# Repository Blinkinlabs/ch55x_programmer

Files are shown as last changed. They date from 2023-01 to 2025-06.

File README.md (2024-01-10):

# CH55x Reset Controller

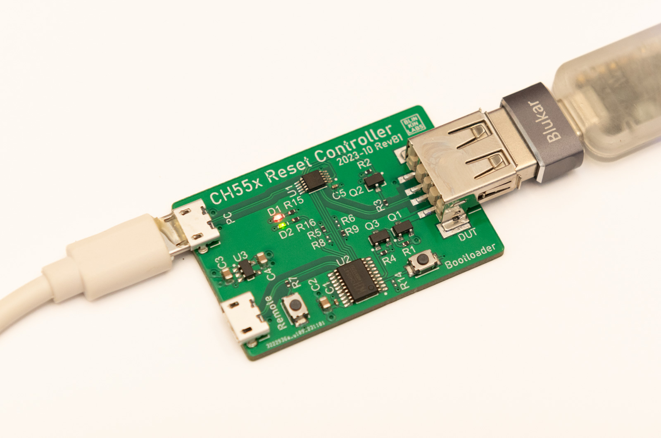
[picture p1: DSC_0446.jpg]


Get yours here: https://shop-nl.blinkinlabs.com/products/ch55x-reset-controller

The CH55x Reset Controller is a one-touch solution for putting WCH CH554 and CH552 microcontrollers into bootloader mode. The reset controller performs a simple sequence to achieve this:

1.    Disconnects both power and USB data lines from the devive
2.    Connects a 10k resistor from 3.3V to the D+ USB line
3.    Connects the power and USB data lines to the device
4.    After a short delay, disconnects the 10k resistor from the device

Notes:

*    This will only work with USB-powered CH55x devices, if the device has power from a battery or other power source, the CH55x will not reset
*    Connect the computer to the 'DUT IN' micro USB port
*    Connect your WCH CH55x device to the 'DUT OUT' USB A port
*    This board was designed to work with 3.3V powered CH55x devices. It may work with 5V powered devices, but this is untested.
*    The board includes a 'control in' connection for remotely controlling the bootloader sequence, however this is not supported in the software for the device.

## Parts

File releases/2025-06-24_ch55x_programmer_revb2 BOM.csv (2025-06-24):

Designator | Quantity | Comment | Description | Manufacturer 1 | Manufacturer Part Number 1 | Supplier 1 | Supplier Part Number 1 | Supplier 2 | Supplier Part Number 2 | Pins | Case/Package | Footprint | Library Name
C1, C5 | 2 | 100nF | CAP SMD 100nF 10% 50V X5R 0402 | Yageo Group | CC0402KRX5R9BB104 | DigiKey | 311-3342-2-ND |  |  | 2 | 0402 | CAPC1005X06L | blinkinlabs.DbLib
C2, C3, C4 | 3 | 10uF | CAP SMD 10uF 10% 25V X5R 0805 | Yageo | CC0805KRX5R8BB106 | Digikey | 13-CC0805KRX5R8BB106TR-ND |  |  | 2 | 0805 | CAPC2012X10L | blinkinlabs.DbLib
D1 | 1 | BL-HUB37A-AV-TRB | LED, 0402, Super Red, 50mcd@20mA, 627~637nm | BrtLed | BL-HUB37A-AV-TRB | LCSC | C165980 |  |  | 2 | 0402 | BL-Hxx37A-AV-TRB | blinkinlabs.DbLib
D2 | 1 | BL-HGE37A-AV-TRB | LED, 0402, Super Yellow Green, 35mcd@20mA, 566~576nm | BrtLed | BL-HGE37A-AV-TRB | LCSC | C165979 |  |  | 2 | 0402 | BL-Hxx37A-AV-TRB | blinkinlabs.DbLib
J1, J3 | 2 | A01SB741B1-267 | Micro USB B type ?????? | Unknown/Generic | Unknown/Generic |  |  |  |  | 11 | SMD | A01SB741B1-267 | blinkinlabs.DbLib
J2 | 1 | 904-241A2032S10100 | USB A connector, SMD, no tabs | Jing Extension of the Electronic | 904-241A2032S10100 | LCSC | C42605 |  |  | 6 | SMD | C42605 | blinkinlabs.DbLib
Q1, Q2 | 2 | AO3401A | MOSFET P-CH 30V 4A SOT23-3L | Alpha & Omega Semiconductor | AO3401A | DigiKey | 785-1001-2-ND | LCSC | C15127 | 3 | SOT-23-3 | AO-SOT-23-3L_V | blinkinlabs.DbLib
Q3 | 1 | AO3400A | MOSFET N-CH 30V 5.7A SOT23-3L | Alpha & Omega Semiconductor | AO3400A | Digikey | 785-1000-2-ND | LCSC | C20917 | 3 | SOT-23-3 | AO-SOT-23-3L_V | blinkinlabs.DbLib
R1, R2, R3, R4, R5, R7, R9 | 7 | 10K | RES SMD 10K OHM 5% 1/16W 0402 | Yageo Group | RC0402JR-0710KL | Digikey | 311-10KJRTR-ND |  |  | 2 | 0402 | ERJ2G(0402)_L | blinkinlabs.DbLib
R15, R16 | 2 | 1K | RES SMD 1K OHM 5% 1/16W 0402 | Yageo Group | RC0402JR-071KL | Digikey | 311-1.0KJRTR-ND |  |  | 2 | 0402 | ERJ2G(0402)_L | blinkinlabs.DbLib
SW1, SW2 | 2 | TS-1185-B-A-B-A | Tactile switch, SPST, 3x4mm, 50mA 160gf 12V, no mounting pins | XKB Connectivity | TS-1185-B-A-B-A | LCSC | C561517 |  |  | 2 | SMD | TS-1185 | blinkinlabs.DbLib
U1 | 1 | FSUSB42MUX | USB Switch IC 1 Channel 10-MSOP | onsemi | FSUSB42MUX | Digikey | FSUSB42MUXCT-ND | LCSC | C11355 | 10 | 10-TFSOP, 10-MSOP (0.118", 3.00mm Width) | FP-846AP-MFG | blinkinlabs.DbLib
U2 | 1 | CH554T | 8-bit enhanced USB microcontroller | WCH | CH554T | LCSC | C2928938 |  |  | 20 | TSSOP-20 | TSOP65P660X110-20N | blinkinlabs.DbLib
U3 | 1 | BL8568CB5ATR33 | 500mA High PSRR, Linear Regulator, w. Output Discharge | Shanghai Belling | BL8568CB5ATR33 | LCSC | C243122 |  |  | 5 | SOT-23-5 | SOT95P280X130-5N-2 | blinkinlabs.DbLib

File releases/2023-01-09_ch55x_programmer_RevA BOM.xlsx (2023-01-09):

Designator | Comment | Manufacturer | PartNumber | Digi-Key Part Number | LCSC PartNumber | Description | Pins | Quantity | Model:Footprint | Case/Package
C1, C5 | 0.10uF | Murata Electronics North America | GRM155R71C104KA88J | 490-6328-1-ND |  | CAP CER 0.1UF 16V X7R 0402 | 2 | 2 |  | 0402
C2, C3 | 10uF | Murata Electronics North America | GRM21BR71A106KE51K, GRM21BR61C106ME15L | 490-6477-1-ND, 490-6474-1-ND |  | CAP CER 10UF 10V X7R 0805, CAP CER 10UF 16V X5R 0805 | 2 | 2 |  | 0805
C4 | 10uF | Murata Electronics North America | GRM188R61A106ME69D | 490-10475-1-ND |  | CAP CER 10UF 10V X5R 0603 | 2 | 1 |  | 0603
J1 | DUT_IN | Unknown/Generic | Unknown/Generic |  |  | Micro USB B type 四脚全插牛角 | 11 | 1 | micro usb B type
J2 | DUT_OUT | LC (立创) | C42605 |  |  | USB A connector, SMD, no tabs | 6 | 1 | USB-A SMD
J3 | CONTROL_IN | Unknown/Generic | Unknown/Generic |  |  | Micro USB B type 四脚全插牛角 | 11 | 1 | micro usb B type
Q1, Q2 | AO3401A | Alpha and Omega |  |  |  | P-Channel MOSFET, 30 V, 4 A, -55 to 150 degC, 3-Pin SOT-23-3L, RoHS, Tape and Reel | 3 | 2 | SOT23, 3-Leads, Body 3.1x1.8mm, Pitch 0.95mm
Q3 | AO3400A |  |  |  |  | MOSFET N-CH 30V 5.7A SOT23 | 3 | 1 |  | SOT-23
R1, R2, R3, R4, R7, R8, R9 | 10k | Panasonic Electronic Components | ERJ-2GEJ103X | P10KJCT-ND |  | RES SMD 10K OHM 5% 1/10W 0402 | 2 | 7 |  | 0402
R5, R6, R10, R11, R12, R13, R14 | DNP |  | DNP |  |  |  | 2 | 7 |  | 0402
SW1 | BOOTLOADER | XKB | TS-1185 |  |  | Tact Switch, 3x4mm, no alignment pin, turtle style | 2 | 1 | 3x4x2mm Tact Switch, no alignment pin
SW2 | TS-1185 | XKB | TS-1185 |  |  | Tact Switch, 3x4mm, no alignment pin, turtle style | 2 | 1 | 3x4x2mm Tact Switch, no alignment pin
U1 | FSUSB42MUX |  |  |  |  | IC USB SWITCH DPDT 10MSOP | 10 | 1 |  | MSOP
U2 | CH554T | WCH | CH554T |  |  | 8-bit enhanced USB microcontroller | 20 | 1 | TSOP, 20-Leads, Body 6.50x4.40mm, Pitch 0.65mm, IPC Medium Density
U3 | BL8568CB5ATR33 | Shanghai Belling | BL8568CB5ATR33 |  | C243122 | 500mA High PSRR, Linear Regulator, w. Output Discharge | 5 | 1 | SOT23, 5-Leads, Body 2.90x2.80mm, Pitch 0.95mm, IPC Medium Density

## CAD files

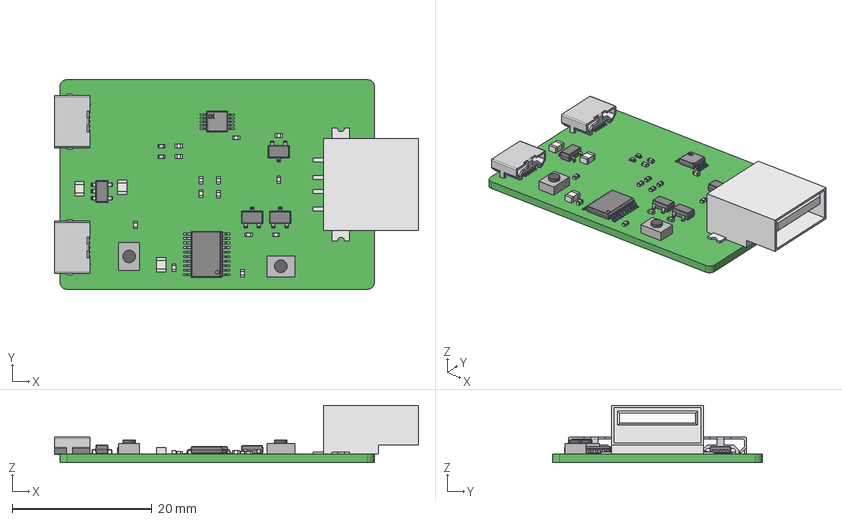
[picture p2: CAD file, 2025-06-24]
releases/2025-06-24_ch55x_programmer_revb2.step
52.1 x 30.0 x 8.23 mm
Extruded x 61
Leader x 34
A01SB741B1-267 v1 x 2
Leg
On-Semi Yury adjustable
On-Semi Yury adjustable - Copy
C42605 v2

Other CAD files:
releases/2023-12-19_ch55x_programmer_revb2.step
releases/2023-11-15_ch55x_programmer_revb2.step
releases/2023-10-30_c55x_programmer_revb.step
releases/2023-10-31_ch55x_programmer_revb1.step
releases/2023-01-09_ch55x_programmer_RevA.step

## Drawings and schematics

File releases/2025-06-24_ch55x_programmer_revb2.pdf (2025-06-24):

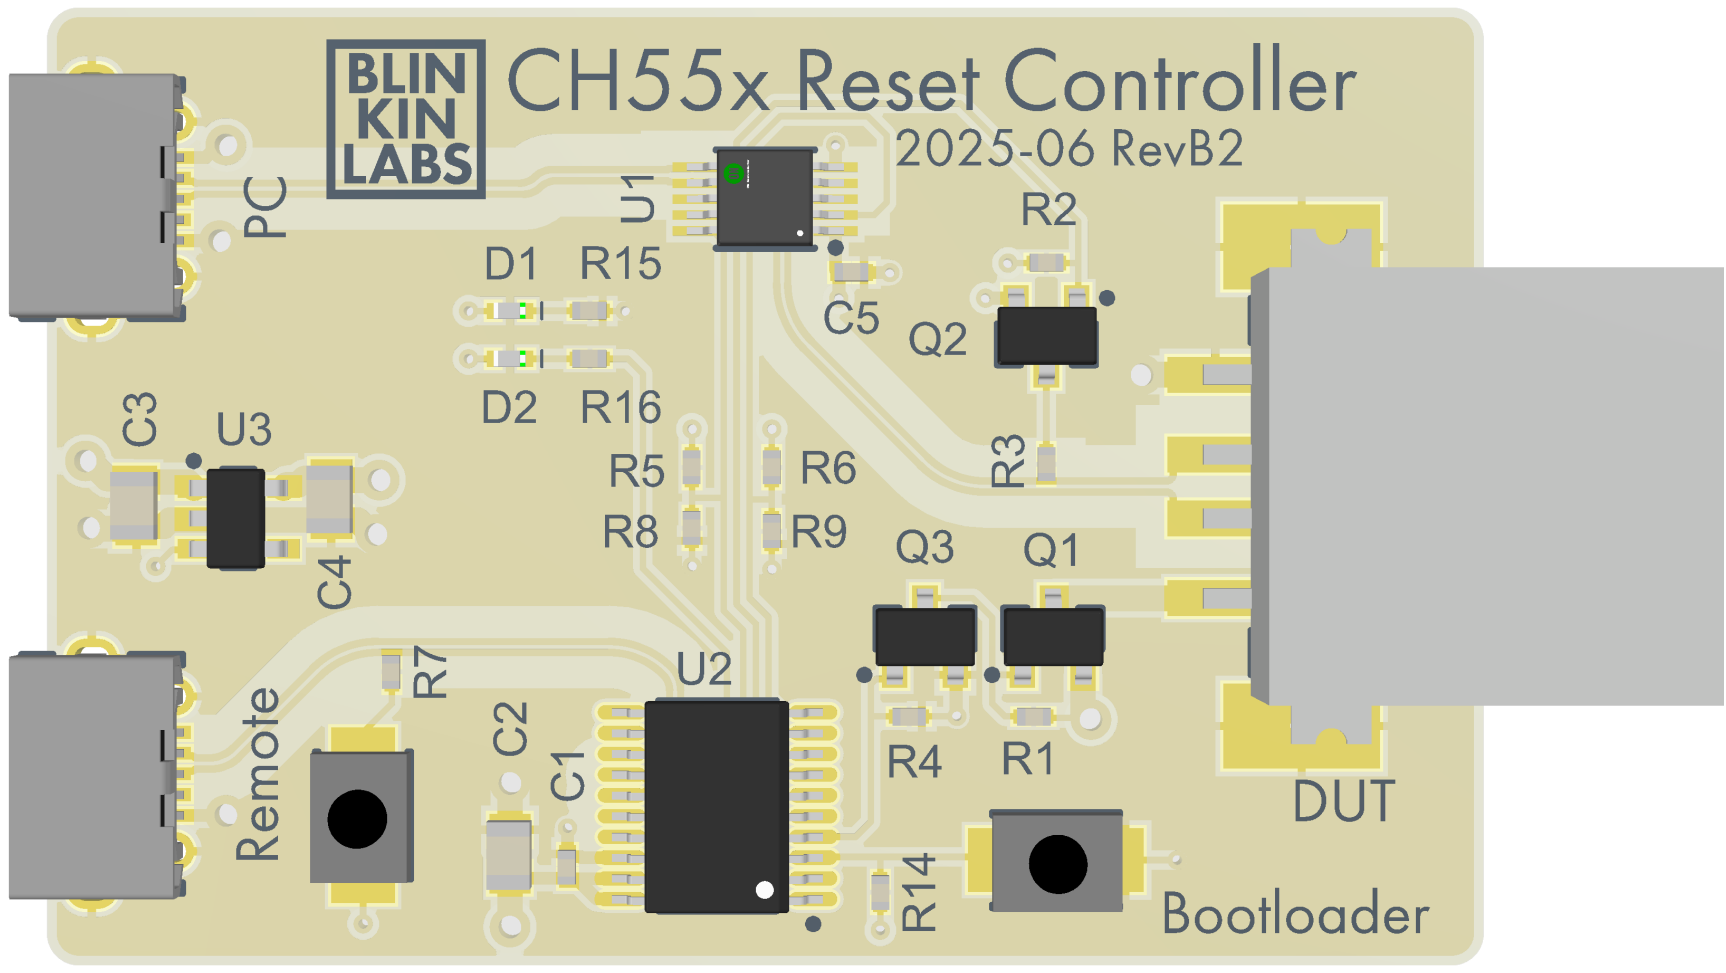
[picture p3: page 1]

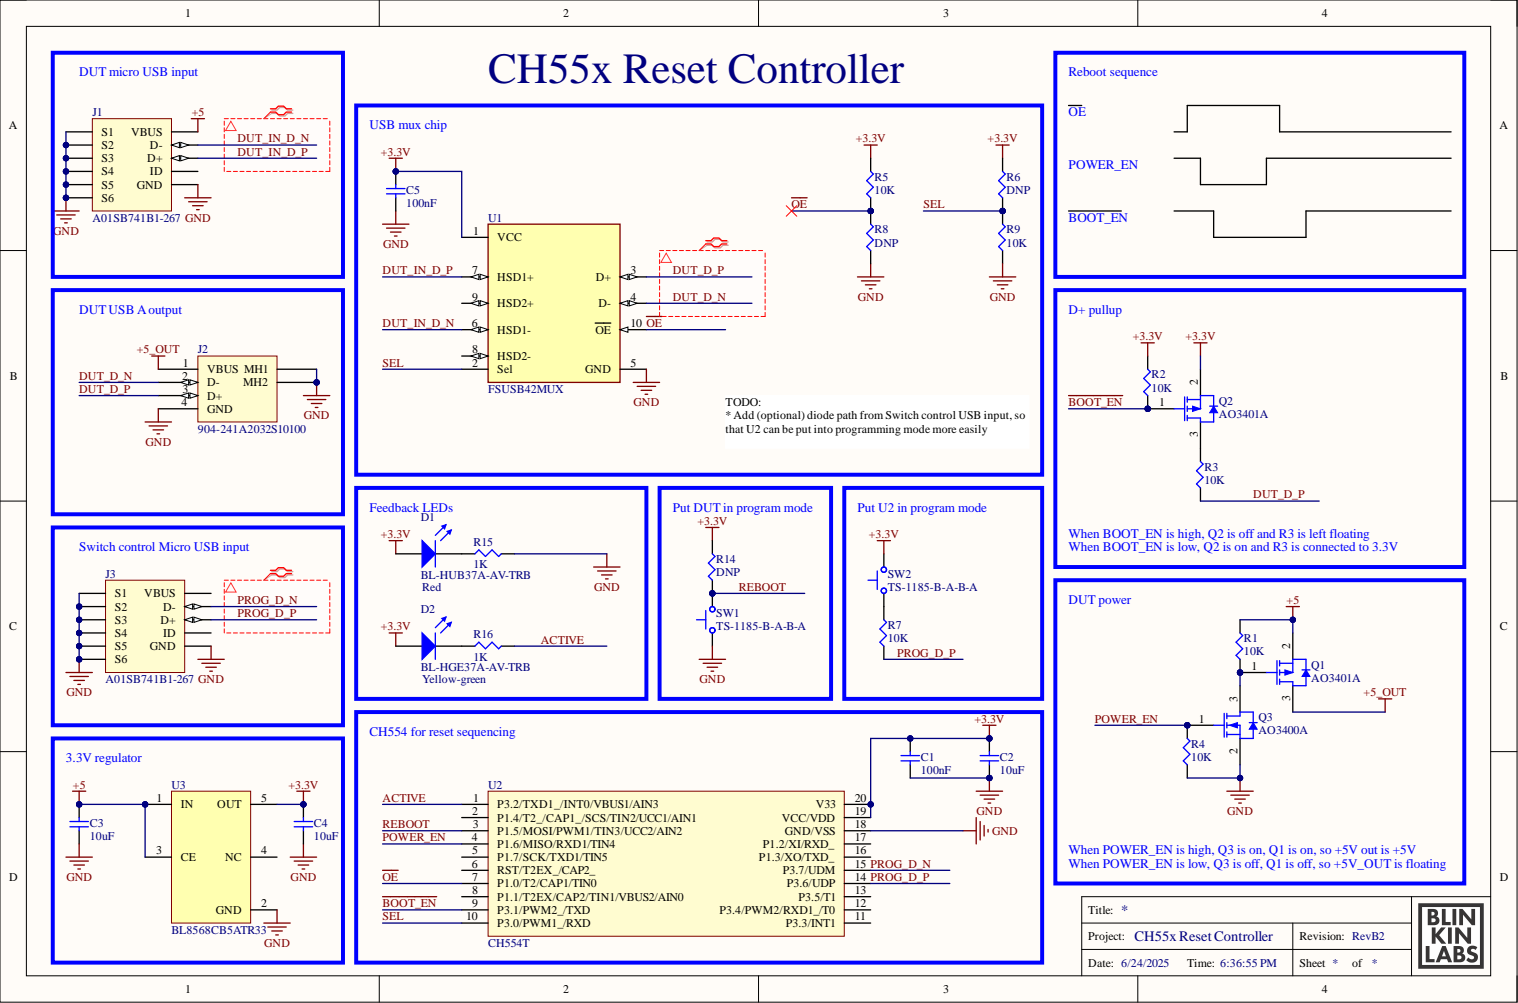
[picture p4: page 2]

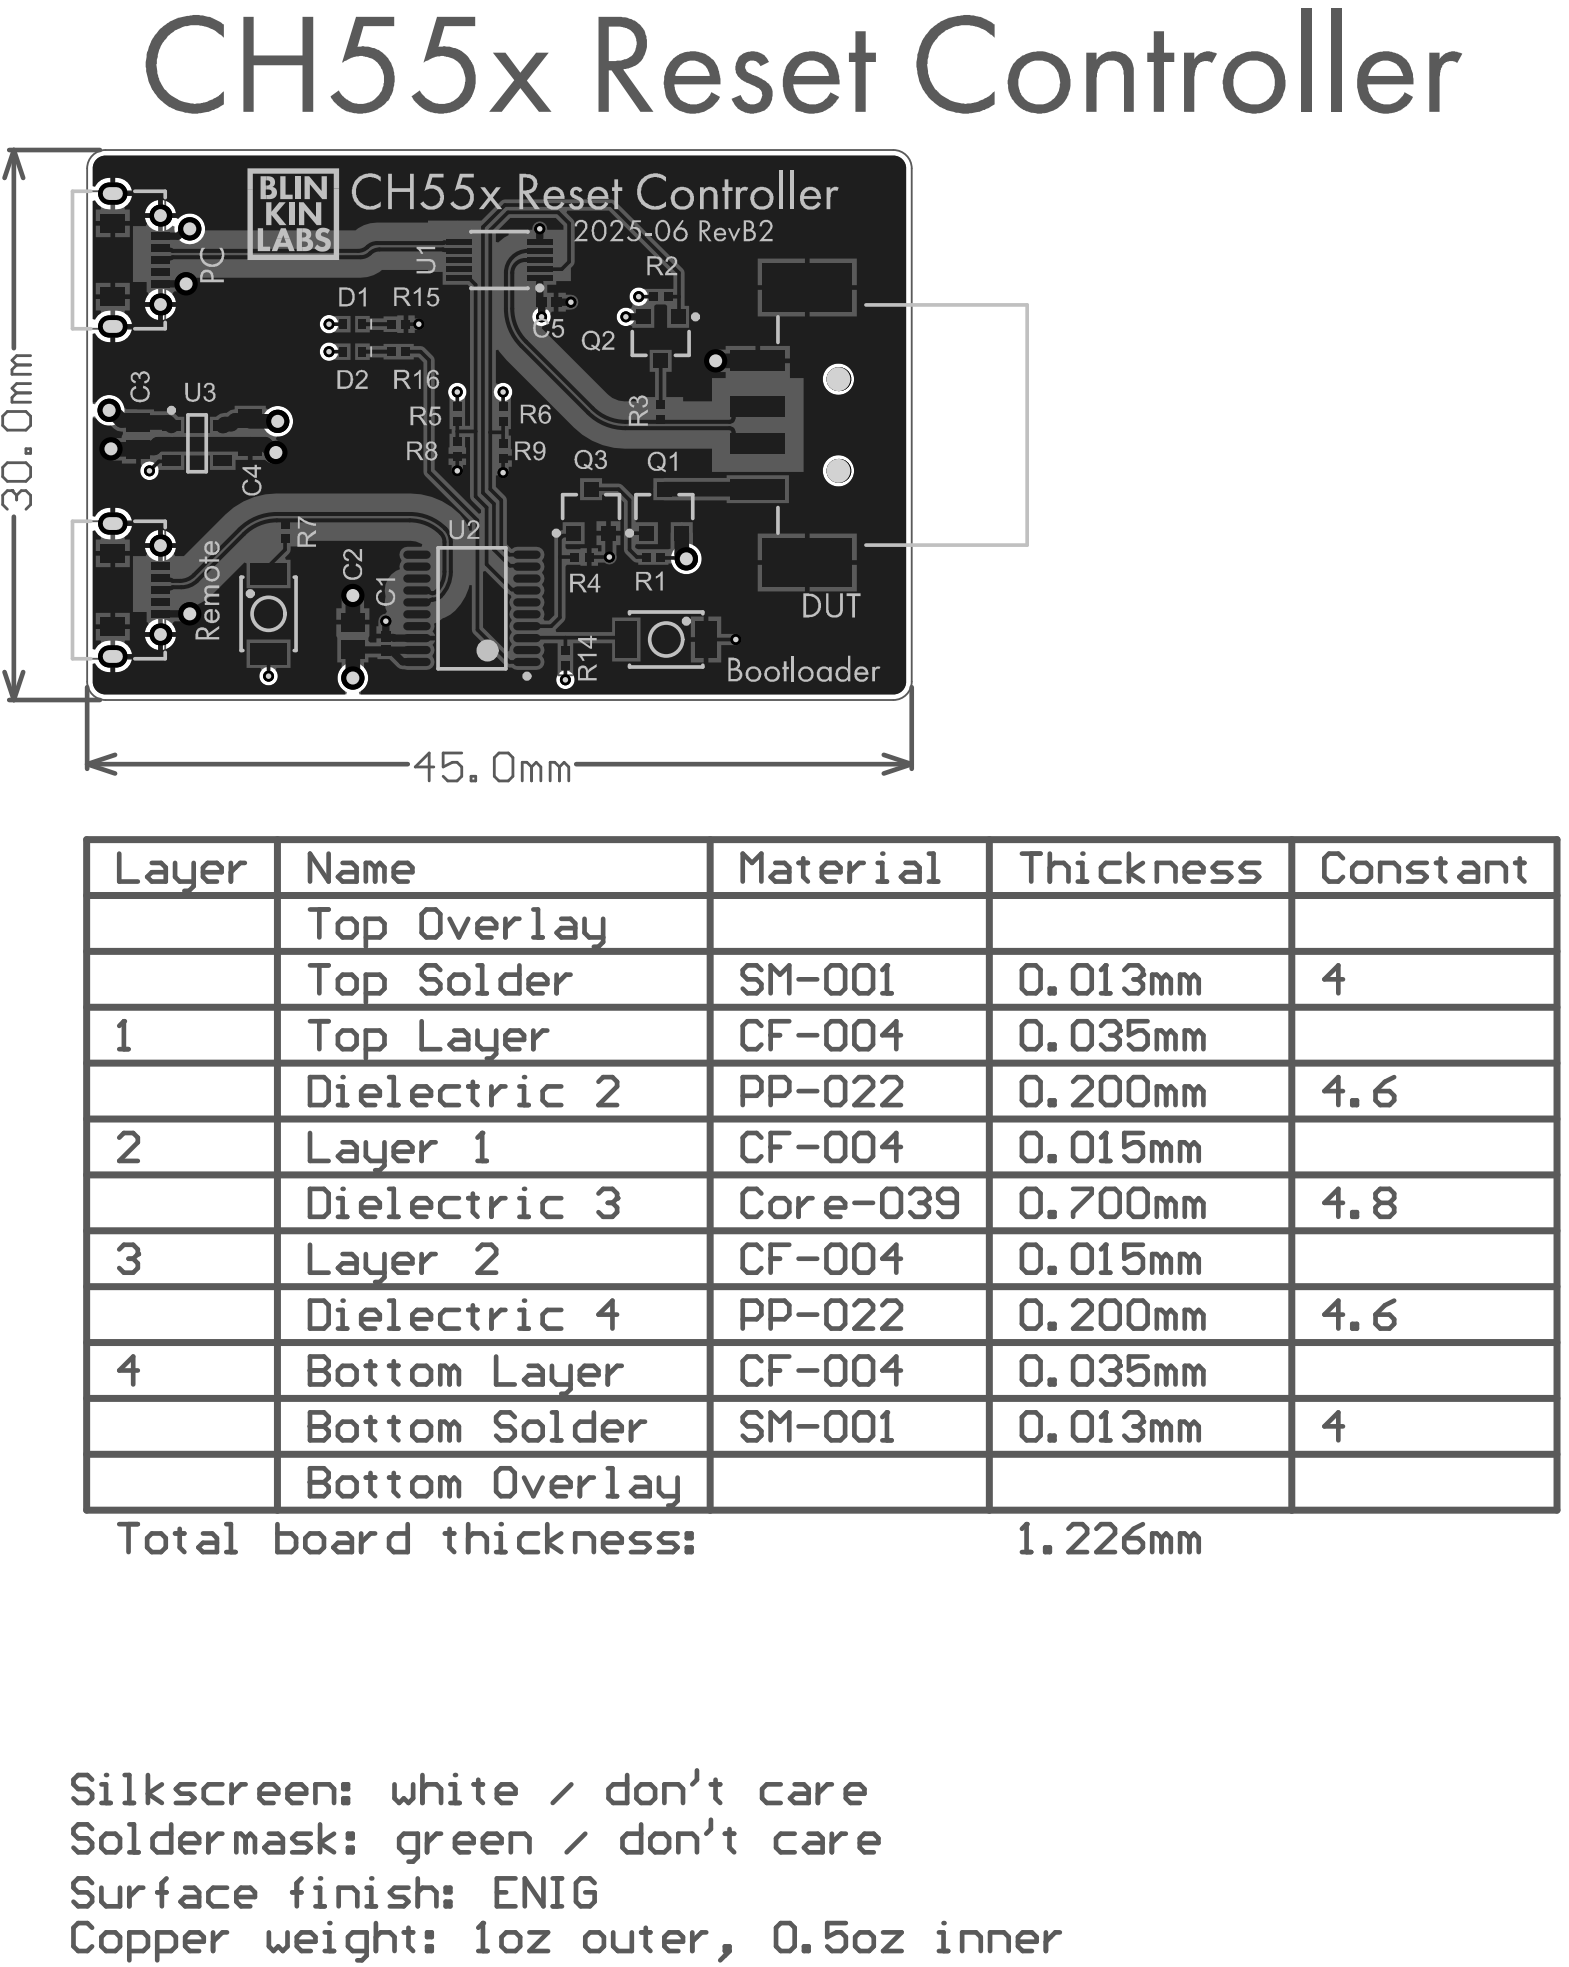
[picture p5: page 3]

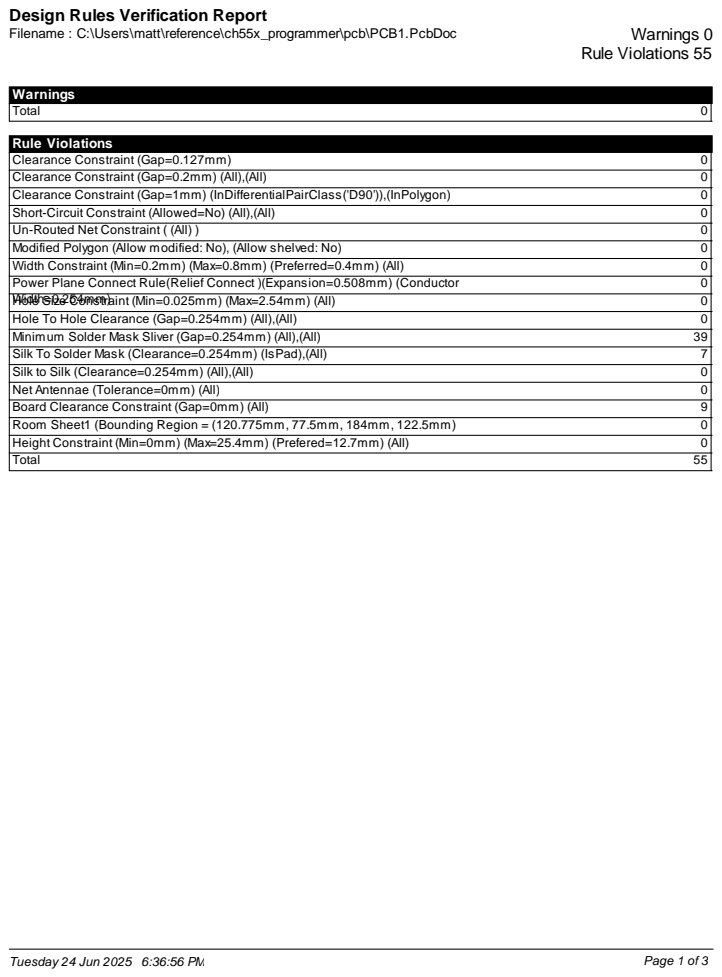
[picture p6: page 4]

Design Rules Verification Report

Rule Violations
Power Plane Connect Rule(Relief Connect )(Expansion=0.508mm) (Conductor
Width=0.254mm)

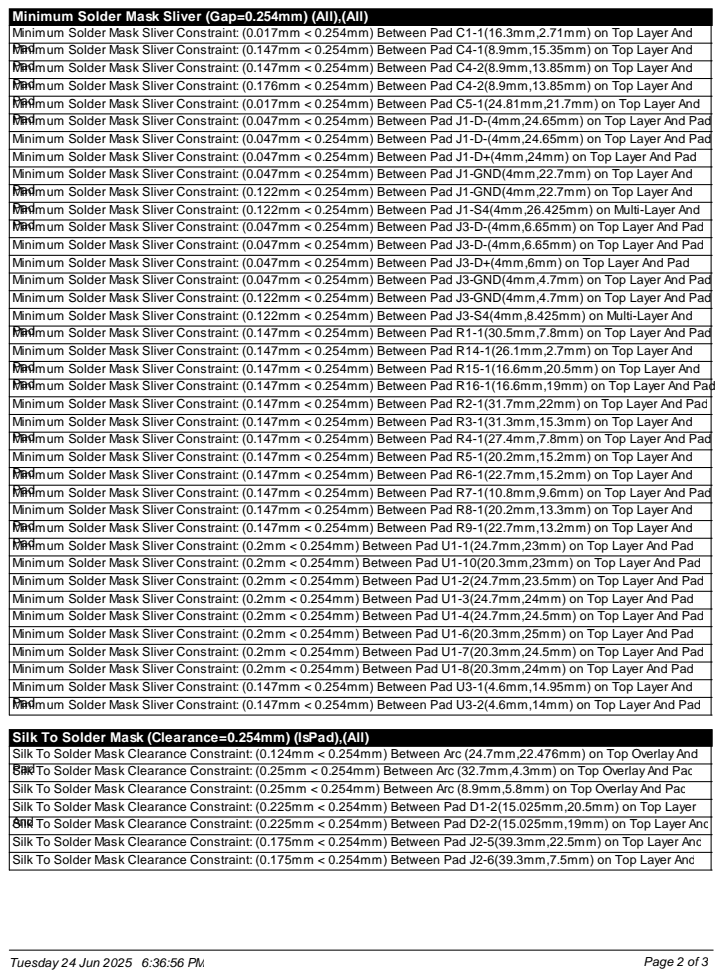
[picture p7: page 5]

Minimum Solder Mask Sliver (Gap=0.254mm) (All),(All)
Minimum Solder Mask Sliver Constraint: (0.017mm < 0.254mm) Between Pad C1-1(16.3mm,2.71mm) on Top Layer And
PaMindimum Solder Mask Sliver Constraint: (0.147mm < 0.254mm) Between Pad C4-1(8.9mm,15.35mm) on Top Layer And
PaMindimum Solder Mask Sliver Constraint: (0.147mm < 0.254mm) Between Pad C4-2(8.9mm,13.85mm) on Top Layer And
PaMindimum Solder Mask Sliver Constraint: (0.176mm < 0.254mm) Between Pad C4-2(8.9mm,13.85mm) on Top Layer And
PaMindimum Solder Mask Sliver Constraint: (0.017mm < 0.254mm) Between Pad C5-1(24.81mm,21.7mm) on Top Layer And
PaMindimum Solder Mask Sliver Constraint: (0.047mm < 0.254mm) Between Pad J1-D-(4mm,24.65mm) on Top Layer And Pad
Minimum Solder Mask Sliver Constraint: (0.047mm < 0.254mm) Between Pad J1-D-(4mm,24.65mm) on Top Layer And Pad
Minimum Solder Mask Sliver Constraint: (0.047mm < 0.254mm) Between Pad J1-D+(4mm,24mm) on Top Layer And Pad
Minimum Solder Mask Sliver Constraint: (0.047mm < 0.254mm) Between Pad J1-GND(4mm,22.7mm) on Top Layer And
PaMindimum Solder Mask Sliver Constraint: (0.122mm < 0.254mm) Between Pad J1-GND(4mm,22.7mm) on Top Layer And
PaMindimum Solder Mask Sliver Constraint: (0.122mm < 0.254mm) Between Pad J1-S4(4mm,26.425mm) on Multi-Layer And
PaMindimum Solder Mask Sliver Constraint: (0.047mm < 0.254mm) Between Pad J3-D-(4mm,6.65mm) on Top Layer And Pad
Minimum Solder Mask Sliver Constraint: (0.047mm < 0.254mm) Between Pad J3-D-(4mm,6.65mm) on Top Layer And Pad
Minimum Solder Mask Sliver Constraint: (0.047mm < 0.254mm) Between Pad J3-D+(4mm,6mm) on Top Layer And Pad
Minimum Solder Mask Sliver Constraint: (0.047mm < 0.254mm) Between Pad J3-GND(4mm,4.7mm) on Top Layer And Pad
Minimum Solder Mask Sliver Constraint: (0.122mm < 0.254mm) Between Pad J3-GND(4mm,4.7mm) on Top Layer And Pad
Minimum Solder Mask Sliver Constraint: (0.122mm < 0.254mm) Between Pad J3-S4(4mm,8.425mm) on Multi-Layer And
PaMindimum Solder Mask Sliver Constraint: (0.147mm < 0.254mm) Between Pad R1-1(30.5mm,7.8mm) on Top Layer And Pad
Minimum Solder Mask Sliver Constraint: (0.147mm < 0.254mm) Between Pad R14-1(26.1mm,2.7mm) on Top Layer And
PaMindimum Solder Mask Sliver Constraint: (0.147mm < 0.254mm) Between Pad R15-1(16.6mm,20.5mm) on Top Layer And
PaMindimum Solder Mask Sliver Constraint: (0.147mm < 0.254mm) Between Pad R16-1(16.6mm,19mm) on Top Layer And Pad
Minimum Solder Mask Sliver Constraint: (0.147mm < 0.254mm) Between Pad R2-1(31.7mm,22mm) on Top Layer And Pad
Minimum Solder Mask Sliver Constraint: (0.147mm < 0.254mm) Between Pad R3-1(31.3mm,15.3mm) on Top Layer And
PaMindimum Solder Mask Sliver Constraint: (0.147mm < 0.254mm) Between Pad R4-1(27.4mm,7.8mm) on Top Layer And Pad
Minimum Solder Mask Sliver Constraint: (0.147mm < 0.254mm) Between Pad R5-1(20.2mm,15.2mm) on Top Layer And
PaMindimum Solder Mask Sliver Constraint: (0.147mm < 0.254mm) Between Pad R6-1(22.7mm,15.2mm) on Top Layer And
PaMindimum Solder Mask Sliver Constraint: (0.147mm < 0.254mm) Between Pad R7-1(10.8mm,9.6mm) on Top Layer And Pad
Minimum Solder Mask Sliver Constraint: (0.147mm < 0.254mm) Between Pad R8-1(20.2mm,13.3mm) on Top Layer And
PaMindimum Solder Mask Sliver Constraint: (0.147mm < 0.254mm) Between Pad R9-1(22.7mm,13.2mm) on Top Layer And
PaMindimum Solder Mask Sliver Constraint: (0.2mm < 0.254mm) Between Pad U1-1(24.7mm,23mm) on Top Layer And Pad
Minimum Solder Mask Sliver Constraint: (0.2mm < 0.254mm) Between Pad U1-10(20.3mm,23mm) on Top Layer And Pad
Minimum Solder Mask Sliver Constraint: (0.2mm < 0.254mm) Between Pad U1-2(24.7mm,23.5mm) on Top Layer And Pad
Minimum Solder Mask Sliver Constraint: (0.2mm < 0.254mm) Between Pad U1-3(24.7mm,24mm) on Top Layer And Pad
Minimum Solder Mask Sliver Constraint: (0.2mm < 0.254mm) Between Pad U1-4(24.7mm,24.5mm) on Top Layer And Pad
Minimum Solder Mask Sliver Constraint: (0.2mm < 0.254mm) Between Pad U1-6(20.3mm,25mm) on Top Layer And Pad
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

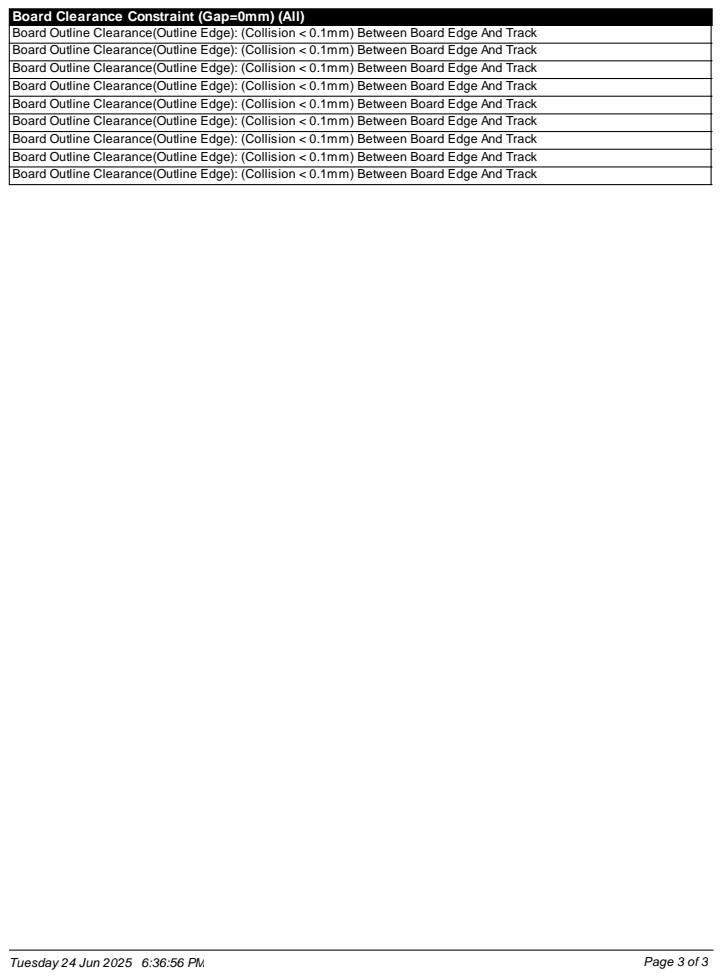
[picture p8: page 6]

Board Clearance Constraint (Gap=0mm) (All)
Board Outline Clearance(Outline Edge): (Collision < 0.1mm) Between Board Edge And Track
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

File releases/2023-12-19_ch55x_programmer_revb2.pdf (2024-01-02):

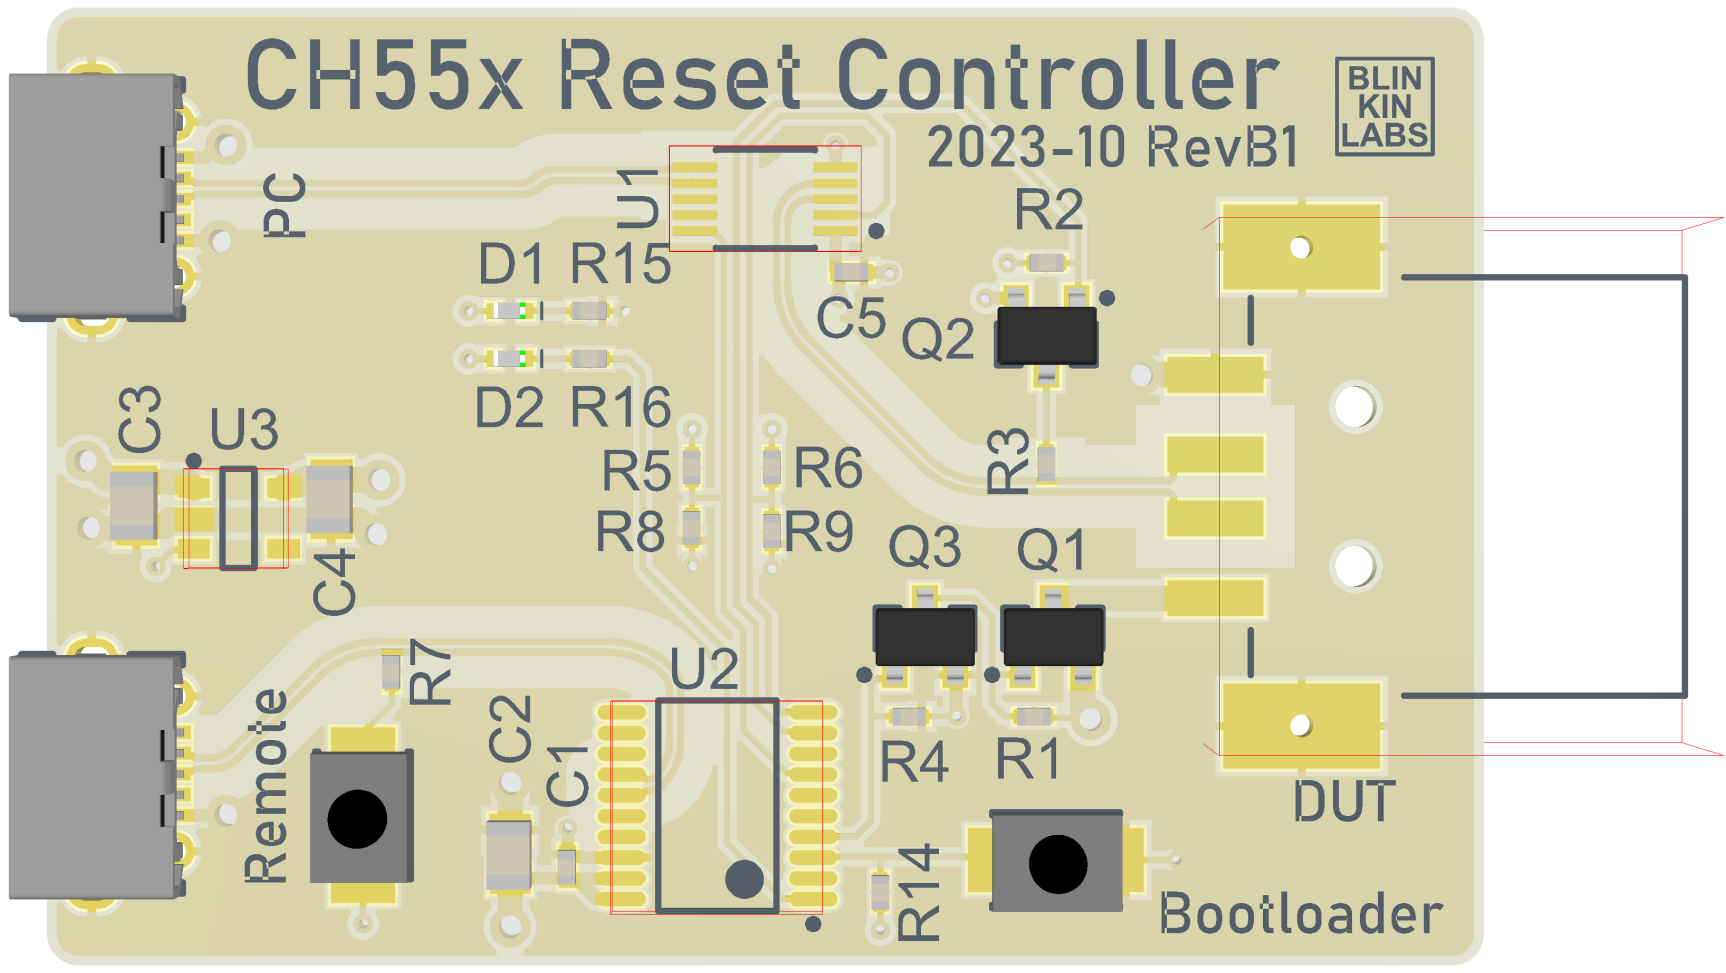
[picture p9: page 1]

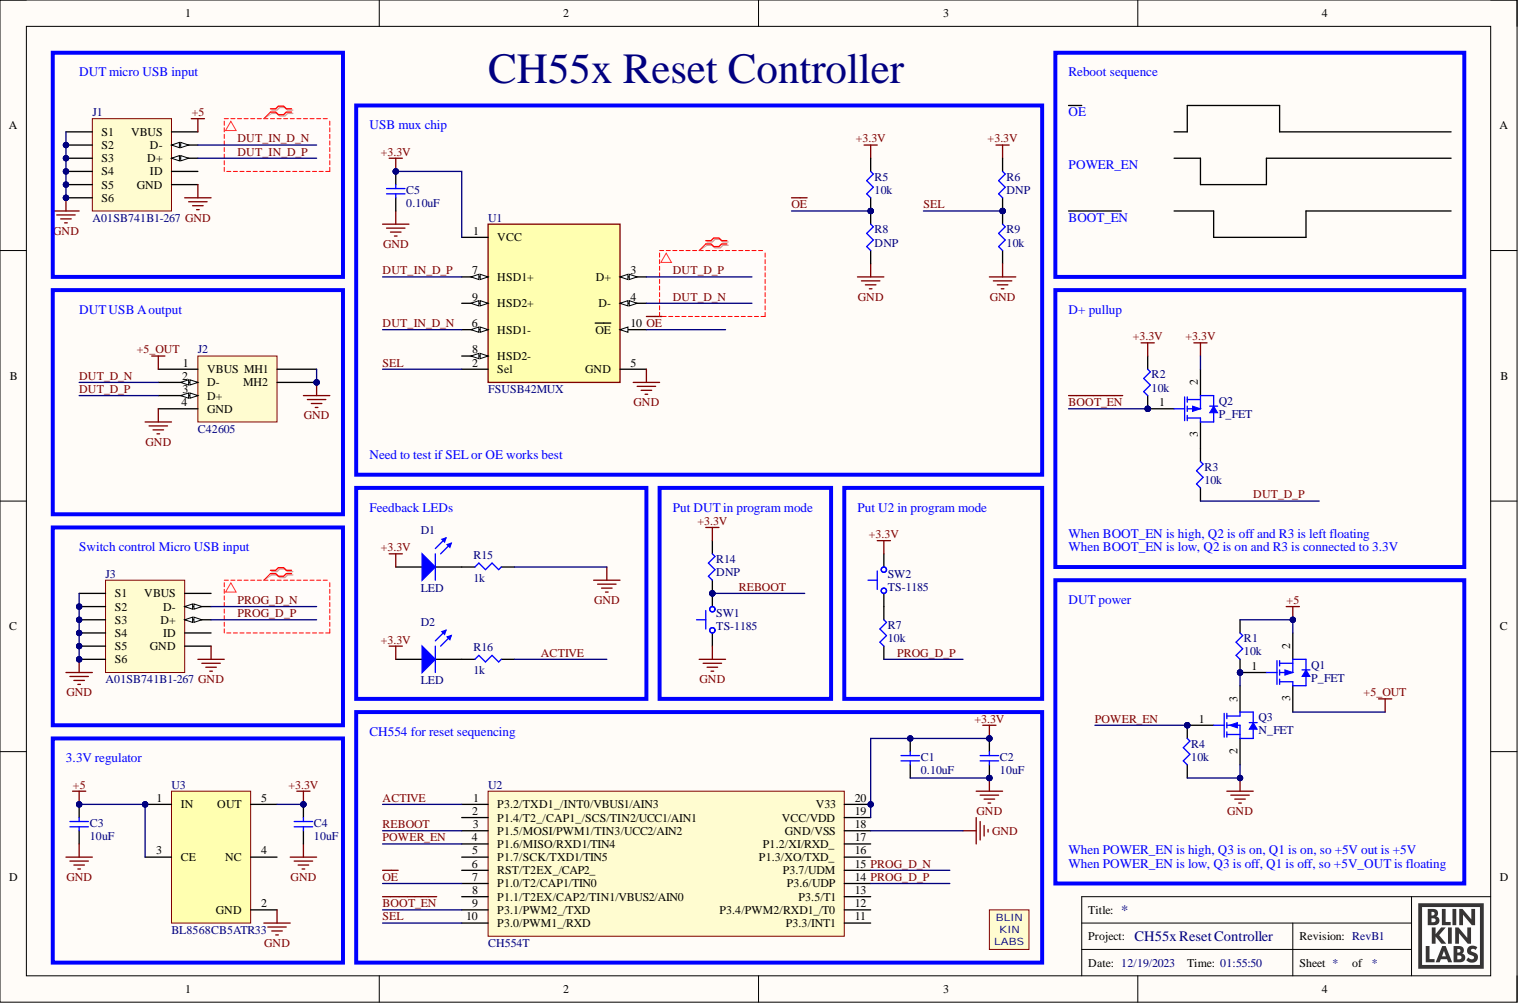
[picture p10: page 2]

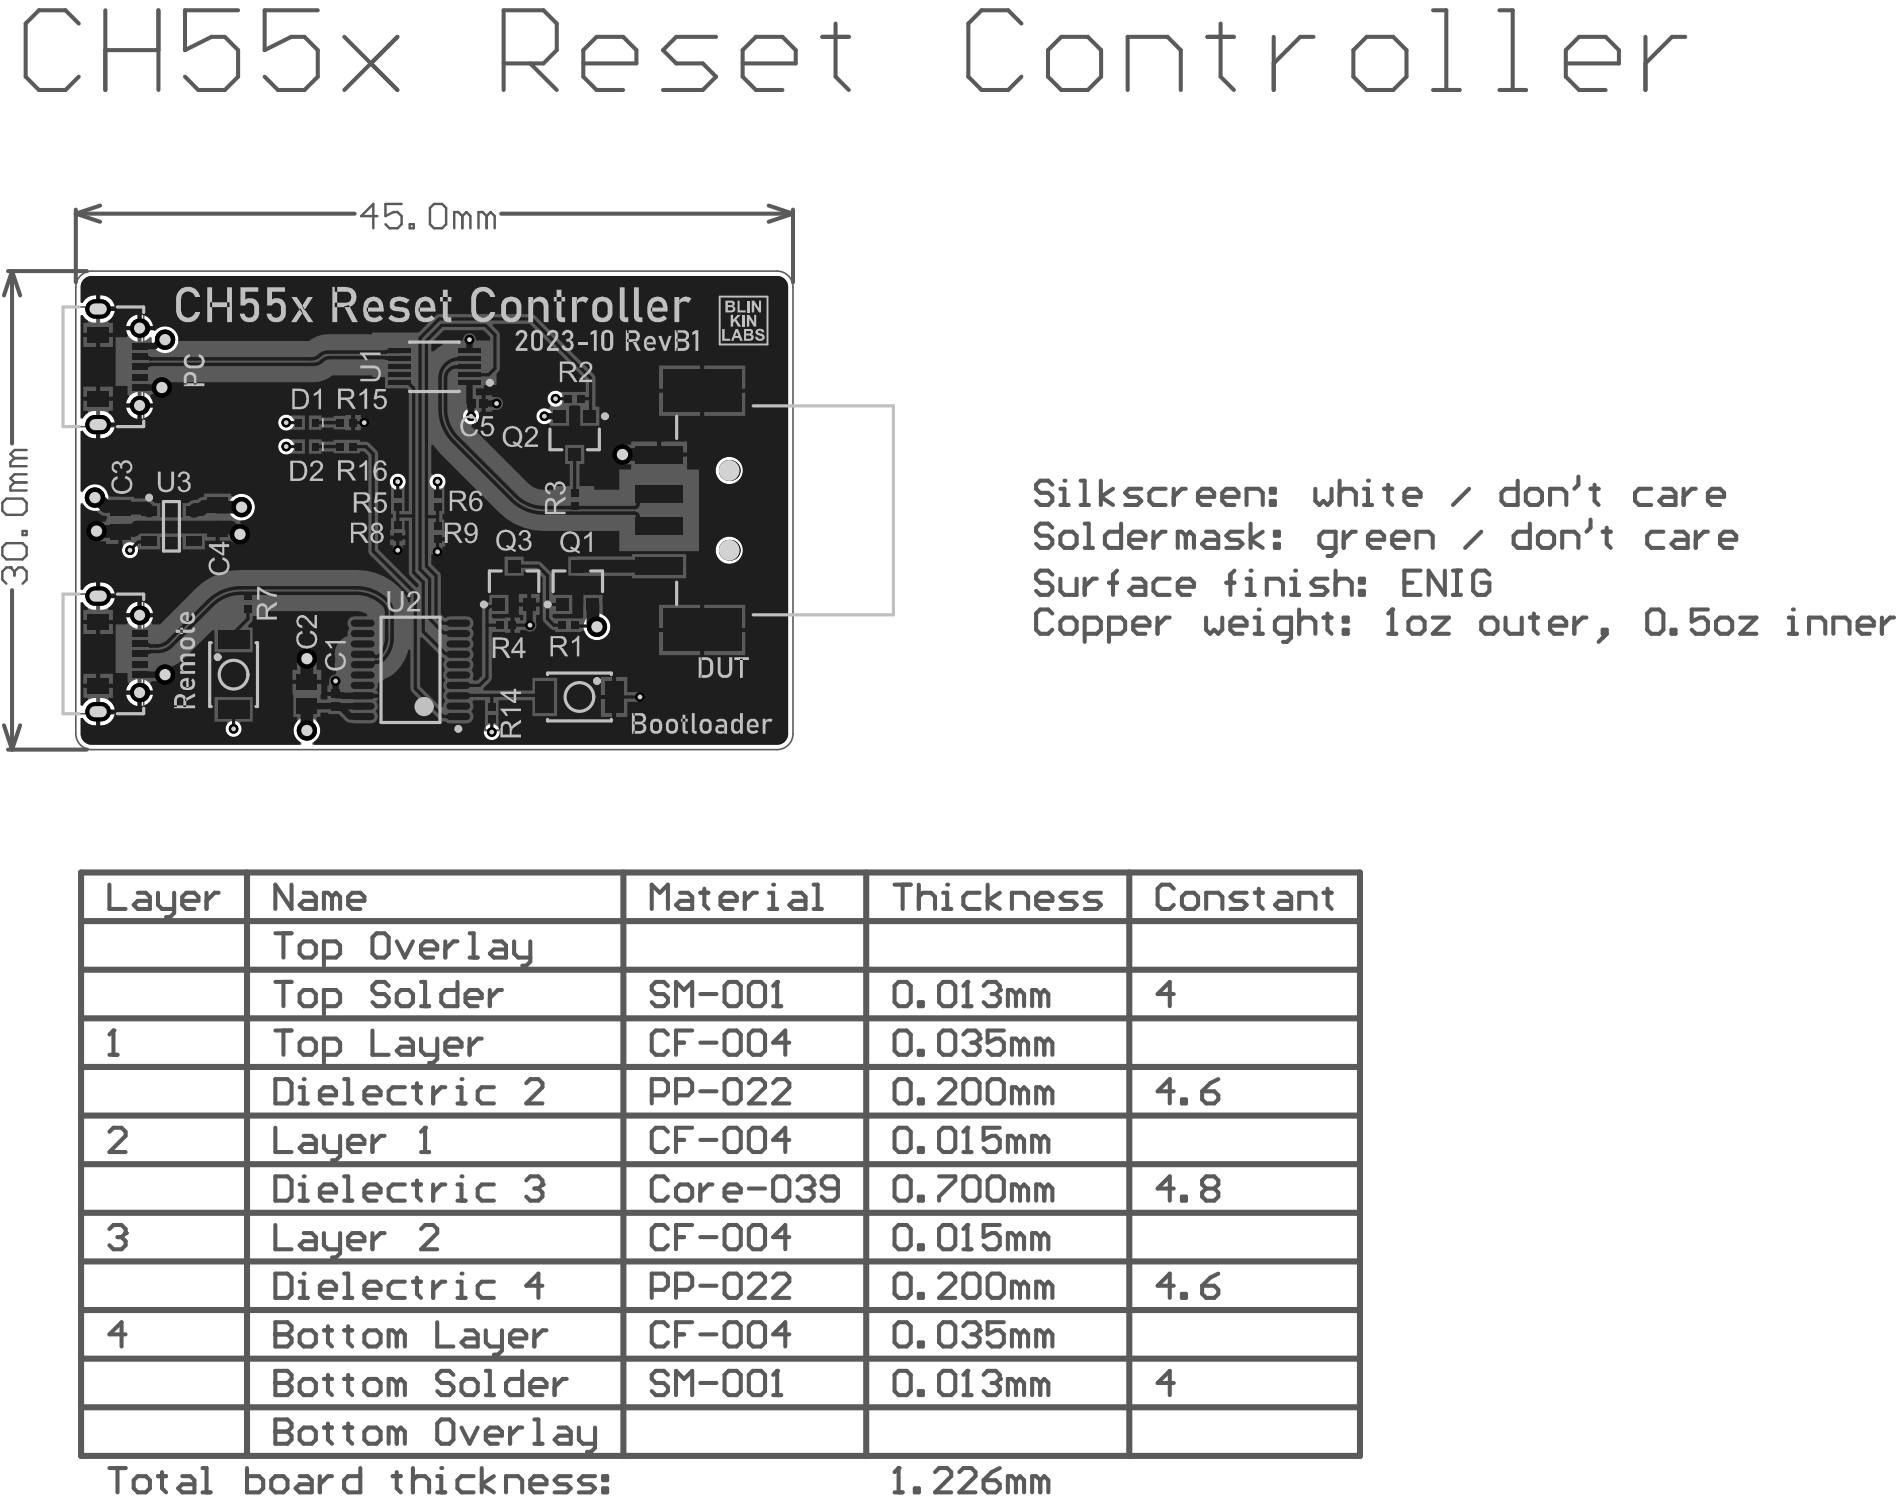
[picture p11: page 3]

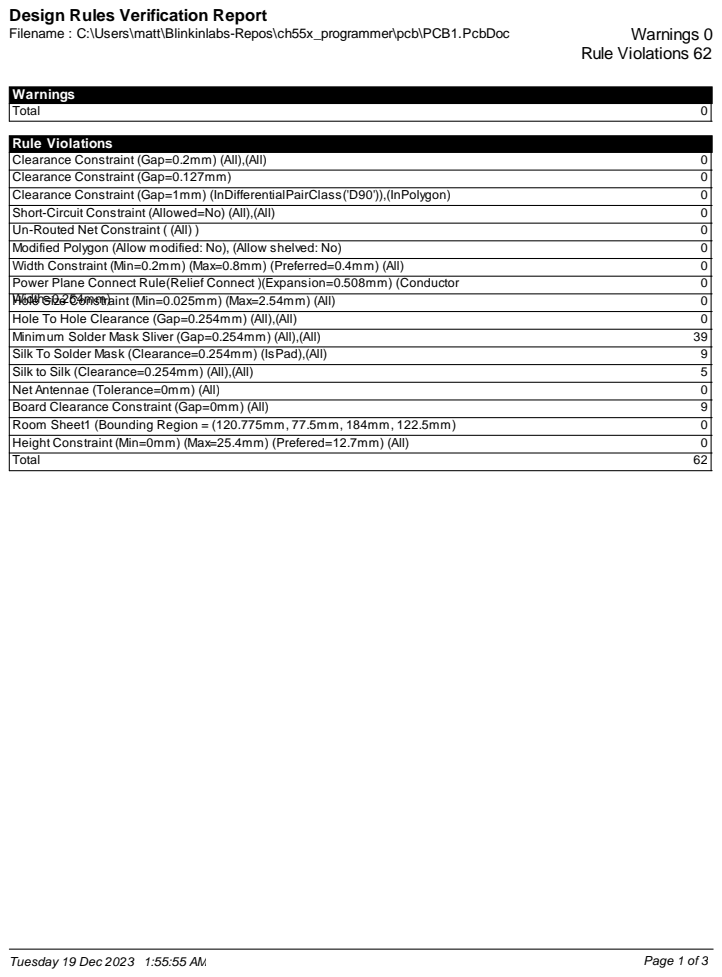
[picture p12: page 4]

Design Rules Verification Report

Rule Violations
Power Plane Connect Rule(Relief Connect )(Expansion=0.508mm) (Conductor
Width=0.254mm)

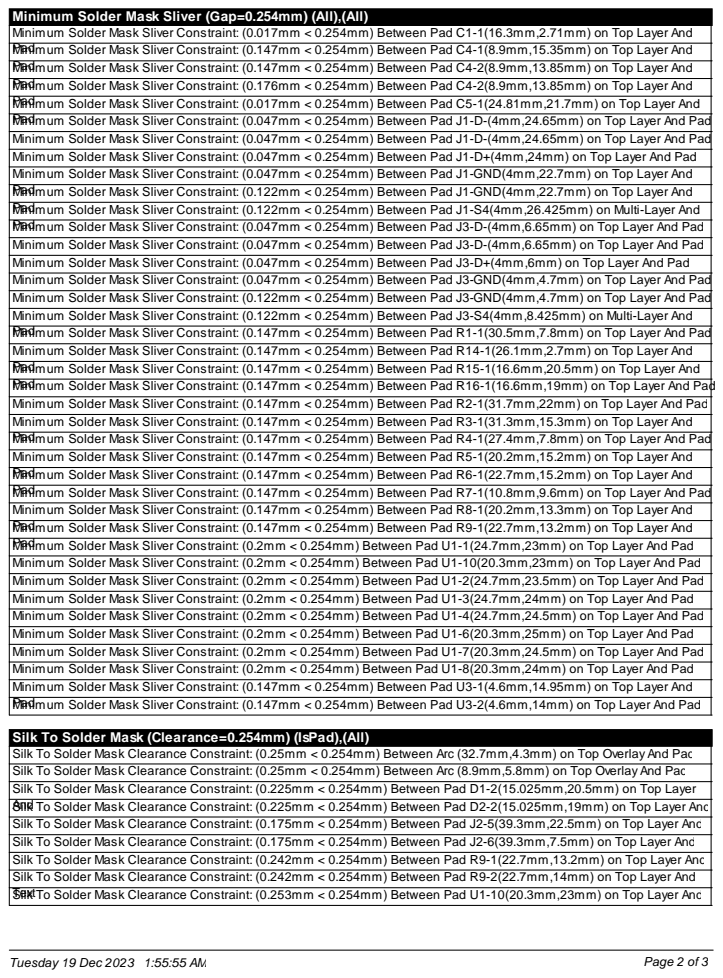
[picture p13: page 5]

Minimum Solder Mask Sliver (Gap=0.254mm) (All),(All)
Minimum Solder Mask Sliver Constraint: (0.017mm < 0.254mm) Between Pad C1-1(16.3mm,2.71mm) on Top Layer And
PaMindimum Solder Mask Sliver Constraint: (0.147mm < 0.254mm) Between Pad C4-1(8.9mm,15.35mm) on Top Layer And
PaMindimum Solder Mask Sliver Constraint: (0.147mm < 0.254mm) Between Pad C4-2(8.9mm,13.85mm) on Top Layer And
PaMindimum Solder Mask Sliver Constraint: (0.176mm < 0.254mm) Between Pad C4-2(8.9mm,13.85mm) on Top Layer And
PaMindimum Solder Mask Sliver Constraint: (0.017mm < 0.254mm) Between Pad C5-1(24.81mm,21.7mm) on Top Layer And
PaMindimum Solder Mask Sliver Constraint: (0.047mm < 0.254mm) Between Pad J1-D-(4mm,24.65mm) on Top Layer And Pad
Minimum Solder Mask Sliver Constraint: (0.047mm < 0.254mm) Between Pad J1-D-(4mm,24.65mm) on Top Layer And Pad
Minimum Solder Mask Sliver Constraint: (0.047mm < 0.254mm) Between Pad J1-D+(4mm,24mm) on Top Layer And Pad
Minimum Solder Mask Sliver Constraint: (0.047mm < 0.254mm) Between Pad J1-GND(4mm,22.7mm) on Top Layer And
PaMindimum Solder Mask Sliver Constraint: (0.122mm < 0.254mm) Between Pad J1-GND(4mm,22.7mm) on Top Layer And
PaMindimum Solder Mask Sliver Constraint: (0.122mm < 0.254mm) Between Pad J1-S4(4mm,26.425mm) on Multi-Layer And
PaMindimum Solder Mask Sliver Constraint: (0.047mm < 0.254mm) Between Pad J3-D-(4mm,6.65mm) on Top Layer And Pad
Minimum Solder Mask Sliver Constraint: (0.047mm < 0.254mm) Between Pad J3-D-(4mm,6.65mm) on Top Layer And Pad
Minimum Solder Mask Sliver Constraint: (0.047mm < 0.254mm) Between Pad J3-D+(4mm,6mm) on Top Layer And Pad
Minimum Solder Mask Sliver Constraint: (0.047mm < 0.254mm) Between Pad J3-GND(4mm,4.7mm) on Top Layer And Pad
Minimum Solder Mask Sliver Constraint: (0.122mm < 0.254mm) Between Pad J3-GND(4mm,4.7mm) on Top Layer And Pad
Minimum Solder Mask Sliver Constraint: (0.122mm < 0.254mm) Between Pad J3-S4(4mm,8.425mm) on Multi-Layer And
PaMindimum Solder Mask Sliver Constraint: (0.147mm < 0.254mm) Between Pad R1-1(30.5mm,7.8mm) on Top Layer And Pad
Minimum Solder Mask Sliver Constraint: (0.147mm < 0.254mm) Between Pad R14-1(26.1mm,2.7mm) on Top Layer And
PaMindimum Solder Mask Sliver Constraint: (0.147mm < 0.254mm) Between Pad R15-1(16.6mm,20.5mm) on Top Layer And
PaMindimum Solder Mask Sliver Constraint: (0.147mm < 0.254mm) Between Pad R16-1(16.6mm,19mm) on Top Layer And Pad
Minimum Solder Mask Sliver Constraint: (0.147mm < 0.254mm) Between Pad R2-1(31.7mm,22mm) on Top Layer And Pad
Minimum Solder Mask Sliver Constraint: (0.147mm < 0.254mm) Between Pad R3-1(31.3mm,15.3mm) on Top Layer And
PaMindimum Solder Mask Sliver Constraint: (0.147mm < 0.254mm) Between Pad R4-1(27.4mm,7.8mm) on Top Layer And Pad
Minimum Solder Mask Sliver Constraint: (0.147mm < 0.254mm) Between Pad R5-1(20.2mm,15.2mm) on Top Layer And
PaMindimum Solder Mask Sliver Constraint: (0.147mm < 0.254mm) Between Pad R6-1(22.7mm,15.2mm) on Top Layer And
PaMindimum Solder Mask Sliver Constraint: (0.147mm < 0.254mm) Between Pad R7-1(10.8mm,9.6mm) on Top Layer And Pad
Minimum Solder Mask Sliver Constraint: (0.147mm < 0.254mm) Between Pad R8-1(20.2mm,13.3mm) on Top Layer And
PaMindimum Solder Mask Sliver Constraint: (0.147mm < 0.254mm) Between Pad R9-1(22.7mm,13.2mm) on Top Layer And
PaMindimum Solder Mask Sliver Constraint: (0.2mm < 0.254mm) Between Pad U1-1(24.7mm,23mm) on Top Layer And Pad
Minimum Solder Mask Sliver Constraint: (0.2mm < 0.254mm) Between Pad U1-10(20.3mm,23mm) on Top Layer And Pad
Minimum Solder Mask Sliver Constraint: (0.2mm < 0.254mm) Between Pad U1-2(24.7mm,23.5mm) on Top Layer And Pad
Minimum Solder Mask Sliver Constraint: (0.2mm < 0.254mm) Between Pad U1-3(24.7mm,24mm) on Top Layer And Pad
Minimum Solder Mask Sliver Constraint: (0.2mm < 0.254mm) Between Pad U1-4(24.7mm,24.5mm) on Top Layer And Pad
Minimum Solder Mask Sliver Constraint: (0.2mm < 0.254mm) Between Pad U1-6(20.3mm,25mm) on Top Layer And Pad
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

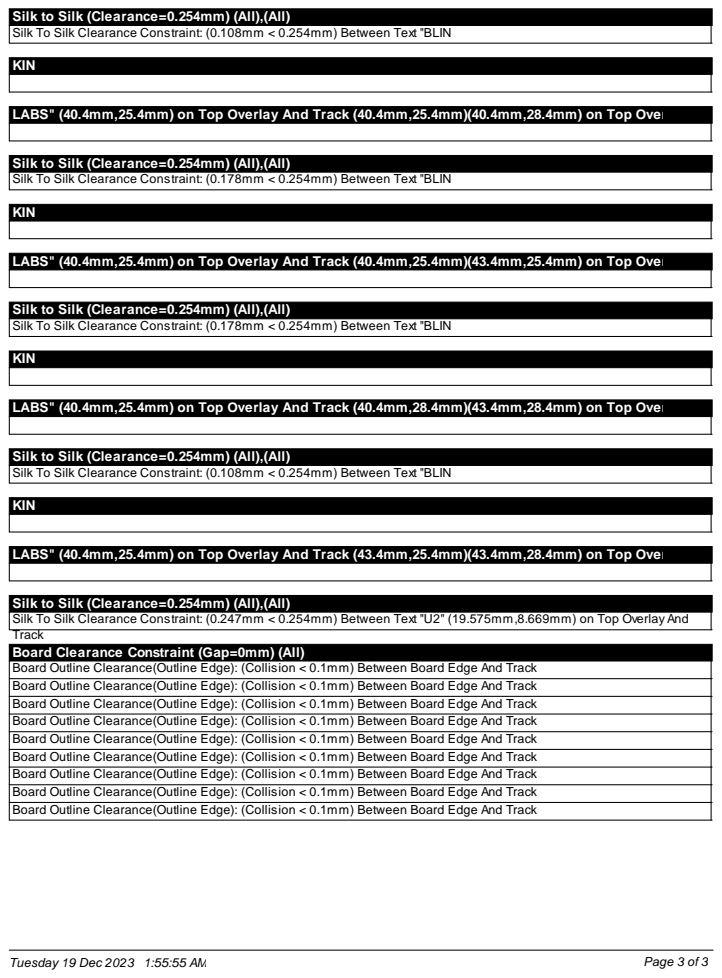
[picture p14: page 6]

Silk to Silk (Clearance=0.254mm) (All),(All)
Silk To Silk Clearance Constraint: (0.108mm < 0.254mm) Between Text "BLIN

LABS" (40.4mm,25.4mm) on Top Overlay And Track (40.4mm,25.4mm)(40.4mm,28.4mm) on Top Overl

Silk To Silk Clearance Constraint: (0.178mm < 0.254mm) Between Text "BLIN
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

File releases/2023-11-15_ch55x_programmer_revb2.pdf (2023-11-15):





Design Rules Verification Report


Minimum Solder Mask Sliver (Gap=0.254mm) (All),(All)
Minimum Solder Mask Sliver Constraint: (0.017mm < 0.254mm) Between Pad C1-1(16.3mm,2.71mm) on Top Layer And Pad
Minimum Solder Mask Sliver Constraint: (0.147mm < 0.254mm) Between Pad C4-1(8.9mm,15.35mm) on Top Layer And Pad
Minimum Solder Mask Sliver Constraint: (0.147mm < 0.254mm) Between Pad C4-2(8.9mm,13.85mm) on Top Layer And Pad
Minimum Solder Mask Sliver Constraint: (0.176mm < 0.254mm) Between Pad C4-2(8.9mm,13.85mm) on Top Layer And Pad
Minimum Solder Mask Sliver Constraint: (0.017mm < 0.254mm) Between Pad C5-1(24.81mm,21.7mm) on Top Layer And Pad
Minimum Solder Mask Sliver Constraint: (0.047mm < 0.254mm) Between Pad J1-D-(4mm,24.65mm) on Top Layer And Pad
Minimum Solder Mask Sliver Constraint: (0.047mm < 0.254mm) Between Pad J1-D+(4mm,24mm) on Top Layer And Pad
Minimum Solder Mask Sliver Constraint: (0.047mm < 0.254mm) Between Pad J1-GND(4mm,22.7mm) on Top Layer And Pad
Minimum Solder Mask Sliver Constraint: (0.122mm < 0.254mm) Between Pad J1-GND(4mm,22.7mm) on Top Layer And Pad
Minimum Solder Mask Sliver Constraint: (0.122mm < 0.254mm) Between Pad J1-S4(4mm,26.425mm) on Multi-Layer And Pad
Minimum Solder Mask Sliver Constraint: (0.047mm < 0.254mm) Between Pad J3-D-(4mm,6.65mm) on Top Layer And Pad
Minimum Solder Mask Sliver Constraint: (0.047mm < 0.254mm) Between Pad J3-D+(4mm,6mm) on Top Layer And Pad
Minimum Solder Mask Sliver Constraint: (0.047mm < 0.254mm) Between Pad J3-GND(4mm,4.7mm) on Top Layer And Pad
Minimum Solder Mask Sliver Constraint: (0.122mm < 0.254mm) Between Pad J3-GND(4mm,4.7mm) on Top Layer And Pad
Minimum Solder Mask Sliver Constraint: (0.122mm < 0.254mm) Between Pad J3-S4(4mm,8.425mm) on Multi-Layer And Pad
Minimum Solder Mask Sliver Constraint: (0.147mm < 0.254mm) Between Pad R1-1(30.5mm,7.8mm) on Top Layer And Pad
Minimum Solder Mask Sliver Constraint: (0.147mm < 0.254mm) Between Pad R14-1(26.1mm,2.7mm) on Top Layer And Pad
Minimum Solder Mask Sliver Constraint: (0.147mm < 0.254mm) Between Pad R15-1(16.6mm,20.5mm) on Top Layer And Pad
Minimum Solder Mask Sliver Constraint: (0.147mm < 0.254mm) Between Pad R16-1(16.6mm,19mm) on Top Layer And Pad
Minimum Solder Mask Sliver Constraint: (0.147mm < 0.254mm) Between Pad R2-1(31.7mm,22mm) on Top Layer And Pad
Minimum Solder Mask Sliver Constraint: (0.147mm < 0.254mm) Between Pad R3-1(31.3mm,15.3mm) on Top Layer And Pad
Minimum Solder Mask Sliver Constraint: (0.147mm < 0.254mm) Between Pad R4-1(27.4mm,7.8mm) on Top Layer And Pad
Minimum Solder Mask Sliver Constraint: (0.147mm < 0.254mm) Between Pad R5-1(20.2mm,15.2mm) on Top Layer And Pad
Minimum Solder Mask Sliver Constraint: (0.147mm < 0.254mm) Between Pad R6-1(22.7mm,15.2mm) on Top Layer And Pad
Minimum Solder Mask Sliver Constraint: (0.147mm < 0.254mm) Between Pad R7-1(10.8mm,9.6mm) on Top Layer And Pad
Minimum Solder Mask Sliver Constraint: (0.147mm < 0.254mm) Between Pad R8-1(20.2mm,13.3mm) on Top Layer And Pad
Minimum Solder Mask Sliver Constraint: (0.147mm < 0.254mm) Between Pad R9-1(22.7mm,13.2mm) on Top Layer And Pad
Minimum Solder Mask Sliver Constraint: (0.2mm < 0.254mm) Between Pad U1-1(24.7mm,23mm) on Top Layer And Pad
Minimum Solder Mask Sliver Constraint: (0.2mm < 0.254mm) Between Pad U1-10(20.3mm,23mm) on Top Layer And Pad
Minimum Solder Mask Sliver Constraint: (0.2mm < 0.254mm) Between Pad U1-2(24.7mm,23.5mm) on Top Layer And Pad
Minimum Solder Mask Sliver Constraint: (0.2mm < 0.254mm) Between Pad U1-3(24.7mm,24mm) on Top Layer And Pad
Minimum Solder Mask Sliver Constraint: (0.2mm < 0.254mm) Between Pad U1-4(24.7mm,24.5mm) on Top Layer And Pad
Minimum Solder Mask Sliver Constraint: (0.2mm < 0.254mm) Between Pad U1-6(20.3mm,25mm) on Top Layer And Pad
Minimum Solder Mask Sliver Constraint: (0.2mm < 0.254mm) Between Pad U1-7(20.3mm,24.5mm) on Top Layer And Pad
Minimum Solder Mask Sliver Constraint: (0.2mm < 0.254mm) Between Pad U1-8(20.3mm,24mm) on Top Layer And Pad
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


Silk to Silk (Clearance=0.254mm) (All),(All)
Silk To Silk Clearance Constraint: (0.106mm < 0.254mm) Between Text "BLIN

LABS" (40.4mm,25.4mm) on Top Overlay And Track (40.4mm,25.4mm)(40.4mm,28.4mm) on Top Overl

Silk To Silk Clearance Constraint: (0.176mm < 0.254mm) Between Text "BLIN

LABS" (40.4mm,25.4mm) on Top Overlay And Track (40.4mm,25.4mm)(43.4mm,25.4mm) on Top Overl
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

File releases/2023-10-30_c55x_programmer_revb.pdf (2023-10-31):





Design Rules Verification Report

Rule Violations
Power Plane Connect Rule(Relief Connect )(Expansion=0.508mm) (Conductor
Width=0.254mm)


Minimum Solder Mask Sliver (Gap=0.254mm) (All),(All)
Minimum Solder Mask Sliver Constraint: (0.017mm < 0.254mm) Between Pad C1-1(16.3mm,2.71mm) on Top Layer And
PaMindimum Solder Mask Sliver Constraint: (0.147mm < 0.254mm) Between Pad C4-1(8.9mm,15.35mm) on Top Layer And
PaMindimum Solder Mask Sliver Constraint: (0.147mm < 0.254mm) Between Pad C4-2(8.9mm,13.85mm) on Top Layer And
PaMindimum Solder Mask Sliver Constraint: (0.176mm < 0.254mm) Between Pad C4-2(8.9mm,13.85mm) on Top Layer And
PaMindimum Solder Mask Sliver Constraint: (0.017mm < 0.254mm) Between Pad C5-1(24.81mm,21.7mm) on Top Layer And
PaMindimum Solder Mask Sliver Constraint: (0.047mm < 0.254mm) Between Pad J1-D-(4mm,24.65mm) on Top Layer And Pad
Minimum Solder Mask Sliver Constraint: (0.047mm < 0.254mm) Between Pad J1-D-(4mm,24.65mm) on Top Layer And Pad
Minimum Solder Mask Sliver Constraint: (0.047mm < 0.254mm) Between Pad J1-D+(4mm,24mm) on Top Layer And Pad
Minimum Solder Mask Sliver Constraint: (0.047mm < 0.254mm) Between Pad J1-GND(4mm,22.7mm) on Top Layer And
PaMindimum Solder Mask Sliver Constraint: (0.122mm < 0.254mm) Between Pad J1-GND(4mm,22.7mm) on Top Layer And
PaMindimum Solder Mask Sliver Constraint: (0.122mm < 0.254mm) Between Pad J1-S4(4mm,26.425mm) on Multi-Layer And
PaMindimum Solder Mask Sliver Constraint: (0.047mm < 0.254mm) Between Pad J3-D-(4mm,6.65mm) on Top Layer And Pad
Minimum Solder Mask Sliver Constraint: (0.047mm < 0.254mm) Between Pad J3-D-(4mm,6.65mm) on Top Layer And Pad
Minimum Solder Mask Sliver Constraint: (0.047mm < 0.254mm) Between Pad J3-D+(4mm,6mm) on Top Layer And Pad
Minimum Solder Mask Sliver Constraint: (0.047mm < 0.254mm) Between Pad J3-GND(4mm,4.7mm) on Top Layer And Pad
Minimum Solder Mask Sliver Constraint: (0.122mm < 0.254mm) Between Pad J3-GND(4mm,4.7mm) on Top Layer And Pad
Minimum Solder Mask Sliver Constraint: (0.122mm < 0.254mm) Between Pad J3-S4(4mm,8.425mm) on Multi-Layer And
PaMindimum Solder Mask Sliver Constraint: (0.147mm < 0.254mm) Between Pad R1-1(30.5mm,7.8mm) on Top Layer And Pad
Minimum Solder Mask Sliver Constraint: (0.147mm < 0.254mm) Between Pad R14-1(26.1mm,2.7mm) on Top Layer And
PaMindimum Solder Mask Sliver Constraint: (0.147mm < 0.254mm) Between Pad R15-1(16.6mm,20.5mm) on Top Layer And
PaMindimum Solder Mask Sliver Constraint: (0.147mm < 0.254mm) Between Pad R16-1(16.6mm,19mm) on Top Layer And Pad
Minimum Solder Mask Sliver Constraint: (0.147mm < 0.254mm) Between Pad R2-1(31.7mm,22mm) on Top Layer And Pad
Minimum Solder Mask Sliver Constraint: (0.147mm < 0.254mm) Between Pad R3-1(31.3mm,15.3mm) on Top Layer And
PaMindimum Solder Mask Sliver Constraint: (0.147mm < 0.254mm) Between Pad R4-1(27.4mm,7.8mm) on Top Layer And Pad
Minimum Solder Mask Sliver Constraint: (0.147mm < 0.254mm) Between Pad R5-1(20.2mm,15.2mm) on Top Layer And
PaMindimum Solder Mask Sliver Constraint: (0.147mm < 0.254mm) Between Pad R6-1(22.7mm,15.2mm) on Top Layer And
PaMindimum Solder Mask Sliver Constraint: (0.147mm < 0.254mm) Between Pad R7-1(10.8mm,9.6mm) on Top Layer And Pad
Minimum Solder Mask Sliver Constraint: (0.147mm < 0.254mm) Between Pad R8-1(20.2mm,13.3mm) on Top Layer And
PaMindimum Solder Mask Sliver Constraint: (0.147mm < 0.254mm) Between Pad R9-1(22.7mm,13.2mm) on Top Layer And
PaMindimum Solder Mask Sliver Constraint: (0.2mm < 0.254mm) Between Pad U1-1(24.7mm,23mm) on Top Layer And Pad
Minimum Solder Mask Sliver Constraint: (0.2mm < 0.254mm) Between Pad U1-10(20.3mm,23mm) on Top Layer And Pad
Minimum Solder Mask Sliver Constraint: (0.2mm < 0.254mm) Between Pad U1-2(24.7mm,23.5mm) on Top Layer And Pad
Minimum Solder Mask Sliver Constraint: (0.2mm < 0.254mm) Between Pad U1-3(24.7mm,24mm) on Top Layer And Pad
Minimum Solder Mask Sliver Constraint: (0.2mm < 0.254mm) Between Pad U1-4(24.7mm,24.5mm) on Top Layer And Pad
Minimum Solder Mask Sliver Constraint: (0.2mm < 0.254mm) Between Pad U1-6(20.3mm,25mm) on Top Layer And Pad
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


Silk to Silk (Clearance=0.254mm) (All),(All)
Silk To Silk Clearance Constraint: (0.108mm < 0.254mm) Between Text "BLIN

LABS" (40.4mm,25.4mm) on Top Overlay And Track (40.4mm,25.4mm)(40.4mm,28.4mm) on Top Overl

Silk To Silk Clearance Constraint: (0.178mm < 0.254mm) Between Text "BLIN
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

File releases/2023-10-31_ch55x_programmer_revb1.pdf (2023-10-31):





Design Rules Verification Report


Minimum Solder Mask Sliver (Gap=0.254mm) (All),(All)
Minimum Solder Mask Sliver Constraint: (0.017mm < 0.254mm) Between Pad C1-1(16.3mm,2.71mm) on Top Layer And Pad
Minimum Solder Mask Sliver Constraint: (0.147mm < 0.254mm) Between Pad C4-1(8.9mm,15.35mm) on Top Layer And Pad
Minimum Solder Mask Sliver Constraint: (0.147mm < 0.254mm) Between Pad C4-2(8.9mm,13.85mm) on Top Layer And Pad
Minimum Solder Mask Sliver Constraint: (0.176mm < 0.254mm) Between Pad C4-2(8.9mm,13.85mm) on Top Layer And Pad
Minimum Solder Mask Sliver Constraint: (0.017mm < 0.254mm) Between Pad C5-1(24.81mm,21.7mm) on Top Layer And Pad
Minimum Solder Mask Sliver Constraint: (0.047mm < 0.254mm) Between Pad J1-D-(4mm,24.65mm) on Top Layer And Pad
Minimum Solder Mask Sliver Constraint: (0.047mm < 0.254mm) Between Pad J1-D+(4mm,24mm) on Top Layer And Pad
Minimum Solder Mask Sliver Constraint: (0.047mm < 0.254mm) Between Pad J1-GND(4mm,22.7mm) on Top Layer And Pad
Minimum Solder Mask Sliver Constraint: (0.122mm < 0.254mm) Between Pad J1-GND(4mm,22.7mm) on Top Layer And Pad
Minimum Solder Mask Sliver Constraint: (0.122mm < 0.254mm) Between Pad J1-S4(4mm,26.425mm) on Multi-Layer And Pad
Minimum Solder Mask Sliver Constraint: (0.047mm < 0.254mm) Between Pad J3-D-(4mm,6.65mm) on Top Layer And Pad
Minimum Solder Mask Sliver Constraint: (0.047mm < 0.254mm) Between Pad J3-D+(4mm,6mm) on Top Layer And Pad
Minimum Solder Mask Sliver Constraint: (0.047mm < 0.254mm) Between Pad J3-GND(4mm,4.7mm) on Top Layer And Pad
Minimum Solder Mask Sliver Constraint: (0.122mm < 0.254mm) Between Pad J3-GND(4mm,4.7mm) on Top Layer And Pad
Minimum Solder Mask Sliver Constraint: (0.122mm < 0.254mm) Between Pad J3-S4(4mm,8.425mm) on Multi-Layer And Pad
Minimum Solder Mask Sliver Constraint: (0.147mm < 0.254mm) Between Pad R1-1(30.5mm,7.8mm) on Top Layer And Pad
Minimum Solder Mask Sliver Constraint: (0.147mm < 0.254mm) Between Pad R14-1(26.1mm,2.7mm) on Top Layer And Pad
Minimum Solder Mask Sliver Constraint: (0.147mm < 0.254mm) Between Pad R15-1(16.6mm,20.5mm) on Top Layer And Pad
Minimum Solder Mask Sliver Constraint: (0.147mm < 0.254mm) Between Pad R16-1(16.6mm,19mm) on Top Layer And Pad
Minimum Solder Mask Sliver Constraint: (0.147mm < 0.254mm) Between Pad R2-1(31.7mm,22mm) on Top Layer And Pad
Minimum Solder Mask Sliver Constraint: (0.147mm < 0.254mm) Between Pad R3-1(31.3mm,15.3mm) on Top Layer And Pad
Minimum Solder Mask Sliver Constraint: (0.147mm < 0.254mm) Between Pad R4-1(27.4mm,7.8mm) on Top Layer And Pad
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

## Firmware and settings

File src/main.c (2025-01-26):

#include <ch554.h>
#include <debug.h>
#include <string.h>
#include <stdio.h>
#include <stdbool.h>

#define SFR_P1 0x90
#define SFR_P3 0xB0

// Pin map:
SBIT(OE_N, SFR_P1, 0);      // OE_N         P1.0   Enable USB switch output (active low)
SBIT(REBOOT_N, SFR_P1, 5);  // REBOOT_N     P1.5   Reboot button input (low when pressed)
SBIT(POWER_EN, SFR_P1, 6);  // POWER_EN     P1.6   Enable power to DUT (active high)
SBIT(SEL, SFR_P3, 0);       // SEL          P3.0   Select USB switch output (keep low)
SBIT(BOOT_EN_N, SFR_P3, 1); // BOOT_EN_N    P3.1   Enable DUT boot resistor (active low)
SBIT(ACTIVE_N, SFR_P3, 2);  // ACTIVE_N     P3.2   Status LED output (active low)

void hw_init() {
    // REBOOT is an input
    REBOOT_N = 1;
    // Quasi-bidirectional, Pn_MOD_OC = 1, Pn_DIR_PU = 1
    P1_MOD_OC = P1_MOD_OC | (1<<5);
    P1_DIR_PU = P1_DIR_PU |	(1<<5);

    // POWER_EN, OE_N, BOOT_EN_N, SEL are outputs
    BOOT_EN_N = 1; // Release pull-up on D+ line
    POWER_EN = 1; // Enable USB power
    OE_N = 0; // Enable USB data lines
    SEL = 0; // Configure USB mux

    // Output mode: Pn_MOD_OC = 0, Pn_DIR_PU = 1
    P1_MOD_OC = P1_MOD_OC & ~((1<<0) | (1<<6));
    P1_DIR_PU = P1_DIR_PU |	((1<<0) | (1<<6));
    P3_MOD_OC = P3_MOD_OC & ~((1<<2) | (1<<0) | (1<<1));
    P3_DIR_PU = P3_DIR_PU |	((1<<2) | (1<<0) | (1<<1));

    ACTIVE_N = 0; // Turn on status LED
}

void reboot_sequence() {
    ACTIVE_N = 1; // Turn off status LED

    OE_N = 1; // Disable USB data lines
    POWER_EN = 0; // Disable USB power

    mDelaymS(500);   // Give the target time to power down

    BOOT_EN_N = 0; // Enable pull-up on D+ line
    POWER_EN = 1; // Enable USB power
    OE_N = 0; // Enable USB data lines

    mDelaymS(500);   // Give the target time to boot into bootloader

    BOOT_EN_N = 1; // Release pull-up on D+ line

    ACTIVE_N = 0; // Turn on status LED
}

void main() {
    CfgFsys();          // Configure oscillator

    hw_init();

    while (true) {
        if(REBOOT_N == 0) {
            reboot_sequence();
        }
    }
}

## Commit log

2023-01-09 First release
    [PCB1.PcbDoc, Sheet1.SchDoc, ch55x_programmer.PrjPcb]
2023-01-09 Add release files
    [2023-01-09_ch55x_programmer_RevA BOM.xlsx, 2023-01-09_ch55x_programmer_RevA Pick Place.csv, 2023-01-09_ch55x_programmer_RevA.step]
2023-10-30 RevB
    * Update all components to new library
    * Fix BOM
    [PCB1.PcbDoc, Sheet1.SchDoc, ch55x_programmer.PrjPcb]
2023-10-31 Add more copper area for jlc production
    [2023-10-30_c55x_programmer_revb BOM.csv, 2023-10-30_c55x_programmer_revb Pick Place.csv, 2023-10-30_c55x_programmer_revb.step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]
2023-11-15 Update BOM
    [2023-11-15_ch55x_programmer_revb2 BOM.csv, 2023-11-15_ch55x_programmer_revb2 Pick Place.csv, 2023-11-15_ch55x_programmer_revb2.step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]
2024-01-02 RevB version
    [2023-12-19_ch55x_programmer_revb2 BOM.csv, 2023-12-19_ch55x_programmer_revb2 Pick Place.csv, 2023-12-19_ch55x_programmer_revb2.step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]
2025-01-26 Enable status led?
2025-06-24 Update BOM to new format, re-release
    [2025-06-24_ch55x_programmer_revb2 BOM.csv, 2025-06-24_ch55x_programmer_revb2 Pick Place.csv, 2025-06-24_ch55x_programmer_revb2.step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]
